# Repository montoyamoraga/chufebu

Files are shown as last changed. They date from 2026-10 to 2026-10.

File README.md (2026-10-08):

# chufebu

## About

chufebu is an open source hardware Eurorack power bus board by [piruetas](https://piruetas.xyz). It distributes ±12V, +5V, CV and GATE to five 16-pin Eurorack power headers, each one paired with its own 4-pin Molex KK-396 connector for testing. The design is made in KiCad 10 using only KiCad's standard libraries. Hardware is licensed under CERN-OHL-P-2.0 and documentation under CC-BY-SA-4.0 (see [LICENSE.md](./LICENSE.md)). Documentation, schematic, board render and bill of materials (in Spanish): <https://piruetas.xyz/chufebu/>.

## Acerca de

Bus de alimentación eurorack de [piruetas](https://piruetas.xyz), hecho en KiCad y publicado como hardware de código abierto.

Documentación, esquemático, placa y Bill of materials: <https://piruetas.xyz/chufebu/>.

## Características

- 5 headers de alimentación Eurorack de 16 pines (2x08), conectados en bus.
- Cada header tiene su conector Molex KK-396 de 4 pines, para pruebas: -12V, GND, +5V y +12V.
- Las líneas CV y GATE también van en bus entre los 5 headers.
- Placa de 100 × 45 mm, 2 capas, con 2 agujeros de montaje M3.
- Solamente usa las bibliotecas estándar de KiCad 10: no hace falta instalar bibliotecas adicionales para abrir o modificar el diseño.

## Pines y manual de uso

Los pines de los headers de 16 pines y de los conectores KK-396, cómo conectar chufebu y las advertencias están en el [manual de uso](https://piruetas.xyz/chufebu/#manual-de-uso).

## Revisiones

- `v0.1 rev-a`: fabricada en octubre 2026, todavía sin probar.

## Estructura del repositorio

- [hardware/chufebu-v-0-rev-a](./hardware/chufebu-v-0-rev-a): proyecto de KiCad (esquemático y placa), los archivos fuente del diseño.
- [hardware/chufebu-v-0-rev-a-fab](./hardware/chufebu-v-0-rev-a-fab): gerbers y archivos de taladrado para fabricar la placa.
- [docs](./docs): documentación, publicada en <https://piruetas.xyz/chufebu/>. Las capturas del esquemático y de la placa, y la tabla de Bill of materials, las genera [kicad-retrata](https://github.com/piruetasxyz/kicad-retrata) en cada push (ver [kicad-retrata.yml](./kicad-retrata.yml)).
- [LICENSES](./LICENSES): textos completos de las licencias.

## Fabricación

piruetas vende chufebu armado y probado.

Como es hardware de código abierto, los archivos fuente de KiCad, los archivos de fabricación de [hardware/chufebu-v-0-rev-a-fab](./hardware/chufebu-v-0-rev-a-fab) y la [Bill of materials](https://piruetas.xyz/chufebu/#bill-of-materials-v01-rev-a) están publicados para que cualquiera pueda estudiar, modificar y fabricar el diseño. piruetas no da soporte para unidades fabricadas o armadas por terceros.

## Créditos

- Aarón Montoya-Moraga: investigación, esquemático, PCB, fabricación y documentación.
- Matías Serrano: revisor experto de esquemáticos y PCBs.

## Licencia

chufebu es (c) 2026 piruetas SpA / Aarón Montoya-Moraga.

- Hardware (`hardware/`): [CERN-OHL-P-2.0](./LICENSES/CERN-OHL-P-2.0.txt).
- Documentación (`docs/`): [CC-BY-SA-4.0](./LICENSES/CC-BY-SA-4.0.txt).
- El nombre, logo y marca de piruetas no están cubiertos por estas licencias: ver [LicenseRef-piruetas-branding](./LICENSES/LicenseRef-piruetas-branding.txt).

Ver [LICENSE.md](./LICENSE.md) para los detalles. El repositorio sigue la especificación [REUSE](https://reuse.software/).

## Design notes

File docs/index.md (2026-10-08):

# chufebu

Bus de alimentación eurorack: 5 headers de 16 pines (2x08) con ±12V y +5V, cada uno con su conector Molex KK-396 de 4 pines.

## Revisiones

- `v0.1 rev-a`: fabricada en octubre 2026, todavía sin probar.

## Manual de uso

### Qué necesitas

- Una fuente de alimentación Eurorack con ±12V (y +5V si algún módulo lo usa).
- Cables planos Eurorack de 16 pines (16-16) o de 10 a 16 pines (10-16), uno por módulo.
- Opcional: 2 tornillos M3 y separadores para montar la placa.

### Conexión

1. Con la fuente **apagada**, conecta la fuente a uno de los headers de 16 pines o a uno de los conectores Molex.
2. Conecta cada módulo con un cable plano a cualquiera de los headers de 16 pines.
3. Orienta cada cable con la **franja roja hacia -12V**. El serigrafiado de la placa marca `-12` en un extremo del header.
4. Revisa todas las conexiones antes de encender la fuente.

### Pines

Header de 16 pines (según el estándar Eurorack de Doepfer):

| Pines | Señal |
| --- | --- |
| 1, 2 | -12V |
| 3 a 8 | GND |
| 9, 10 | +12V |
| 11, 12 | +5V |
| 13, 14 | CV |
| 15, 16 | GATE |

Conector Molex KK-396 de 4 pines:

| Pin | Señal |
| --- | --- |
| 1 | -12V |
| 2 | GND |
| 3 | +5V |
| 4 | +12V |

### Advertencias

- Un cable plano conectado al revés puede dañar el módulo o la fuente. Los headers tienen carcasa con muesca de polarización, pero revisa siempre la franja roja, sobre todo en el lado del módulo.
- Conecta y desconecta cables solamente con la fuente apagada.
- chufebu no tiene fusibles ni protección contra polaridad inversa: la protección depende de la fuente y de cada módulo.
- La corriente total disponible la limita la fuente. Suma el consumo de tus módulos en cada línea y no superes lo que entrega la fuente.

## Esquemático y placa (v0.1 rev-a)

Generados automáticamente por GitHub Actions a partir de `hardware/chufebu-v-0-rev-a/chufebu-v-0-rev-a.kicad_sch` y `.kicad_pcb` en cada push que los modifica.

Esquemático de chufebu v0.1 rev-a

Placa de chufebu v0.1 rev-a

Render 3D de la placa:

<video src="./videos/chufebu-placa-3d-giro.mp4" autoplay loop muted playsinline width="540">Render 3D de la placa de chufebu v0.1 rev-a.</video>

## Bill of materials (v0.1 rev-a)

Generado a partir de `hardware/chufebu-v-0-rev-a/chufebu-v-0-rev-a.kicad_sch`.

<!-- BOM_TABLE_START -->

| Referencias | Cantidad | Valor | Huella | Descripción |
| --- | --- | --- | --- | --- |
| J1, J2, J3, J7, J8 | 5 | Conn_02x08_Odd_Even | Connector_IDC:IDC-Header_2x08_P2.54mm_Vertical | Header de alimentación Eurorack (16 pines): box header 2x08, 2.54 mm, vertical, THT, con carcasa y muesca de polarización ([Thonk](https://www.thonk.co.uk/shop/16pin-power-headers-shrouded/)) |
| J4, J5, J6, J9, J10 | 5 | Conn_01x04_Pin | Connector_Molex:Molex_KK-396_5273-04A_1x04_P3.96mm_Vertical | Conector de alimentación (4 pines): Molex KK-396 5273-04A, 1x04, 3.96 mm, vertical, THT |

10 componentes en total.

<!-- BOM_TABLE_END -->

### Placa (PCB)

Fabricar con los gerbers y archivos de taladrado de [`hardware/chufebu-v-0-rev-a-fab`](https://github.com/piruetasxyz/chufebu/tree/main/hardware/chufebu-v-0-rev-a-fab).

| Especificación | Valor |
| --- | --- |
| Capas | 2 |
| Tamaño | 100 × 45 mm |
| Grosor | 1.6 mm |
| Cobre | 35 µm (1 oz) |
| Acabado superficial | HASL sin plomo (LeadFree HASL) |

## Créditos

- Aarón Montoya-Moraga: investigación, esquemático, PCB, fabricación y documentación.
- Matías Serrano: revisor experto de esquemáticos y PCBs.

## Licencia

El hardware está bajo CERN-OHL-P-2.0 y esta documentación bajo CC-BY-SA-4.0. Ver [LICENSE.md](https://github.com/piruetasxyz/chufebu/blob/main/LICENSE.md).

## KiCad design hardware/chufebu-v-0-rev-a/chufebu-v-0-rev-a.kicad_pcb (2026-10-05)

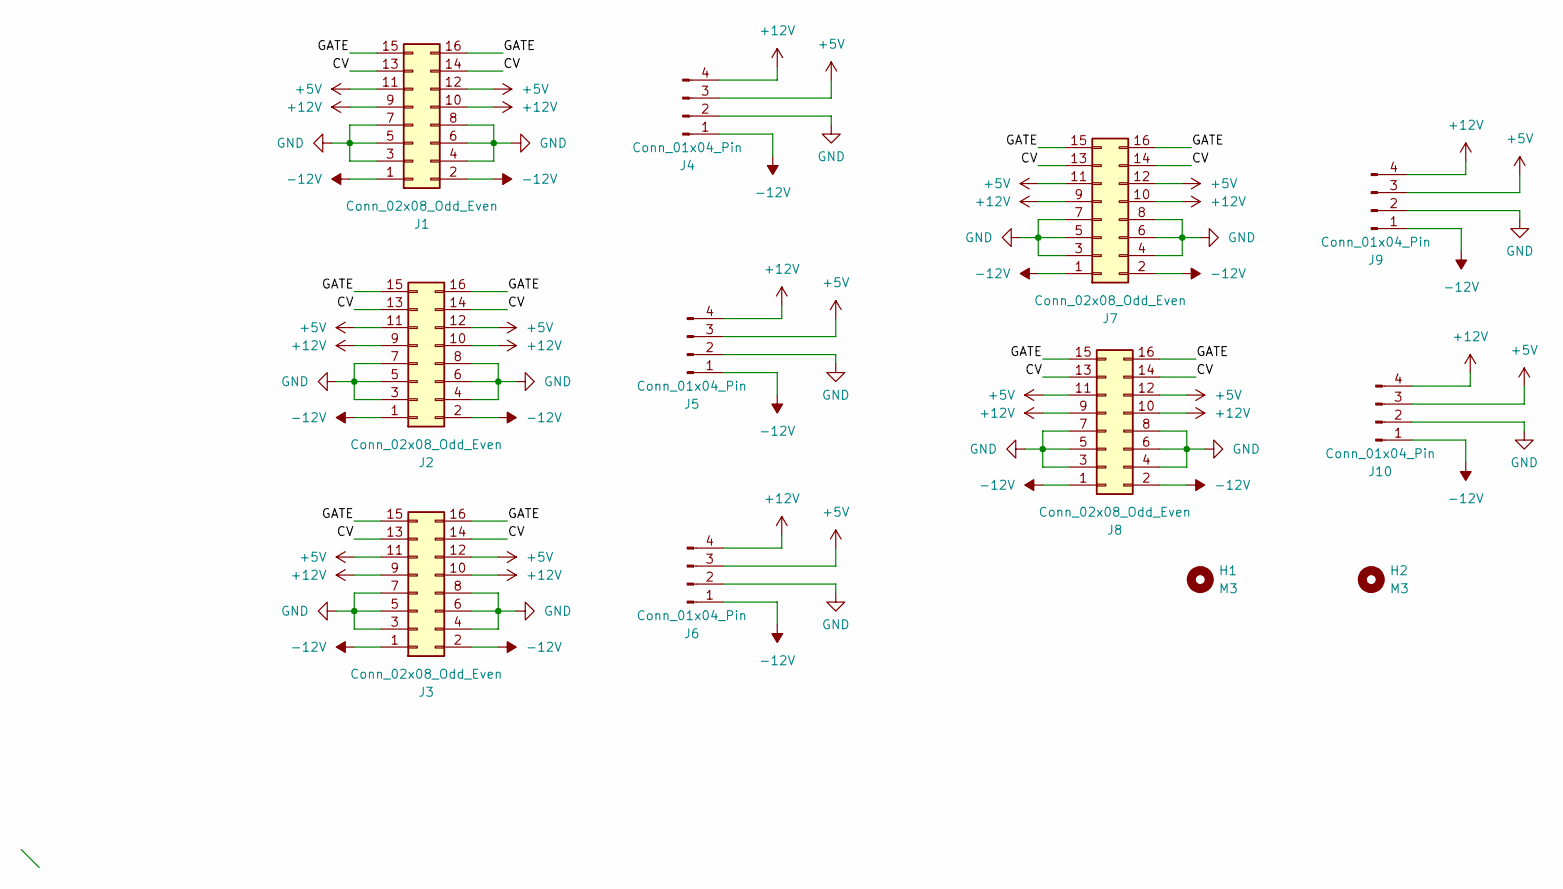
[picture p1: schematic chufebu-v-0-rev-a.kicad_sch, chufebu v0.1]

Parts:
H1, H2: M3; MountingHole_3.2mm_M3
J1, J2, J3, J7, J8: Conn_02x08_Odd_Even; IDC-Header_2x08_P2.54mm_Vertical
J4, J5, J6, J9, J10: Conn_01x04_Pin; Molex_KK-396_5273-04A_1x04_P3.96mm_Vertical

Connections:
+5V: J1.11, J1.12, J2.11, J2.12, J3.11, J3.12, J4.3, J5.3, J6.3, J7.11, J7.12, J8.11, J8.12, J9.3, J10.3
+12V: J1.9, J1.10, J2.9, J2.10, J3.9, J3.10, J4.4, J5.4, J6.4, J7.9, J7.10, J8.9, J8.10, J9.4, J10.4
-12V: J1.1, J1.2, J2.1, J2.2, J3.1, J3.2, J4.1, J5.1, J6.1, J7.1, J7.2, J8.1, J8.2, J9.1, J10.1
/CV: J1.13, J1.14, J2.13, J2.14, J3.13, J3.14, J7.13, J7.14, J8.13, J8.14
/GATE: J1.15, J1.16, J2.15, J2.16, J3.15, J3.16, J7.15, J7.16, J8.15, J8.16
GND: J1.3, J1.4, J1.5, J1.6, J1.7, J1.8, J2.3, J2.4, J2.5, J2.6, J2.7, J2.8, J3.3, J3.4, J3.5, J3.6, J3.7, J3.8, J4.2, J5.2, J6.2, J7.3, J7.4, J7.5, J7.6, J7.7, J7.8, J8.3, J8.4, J8.5, J8.6, J8.7, J8.8, J9.2, J10.2

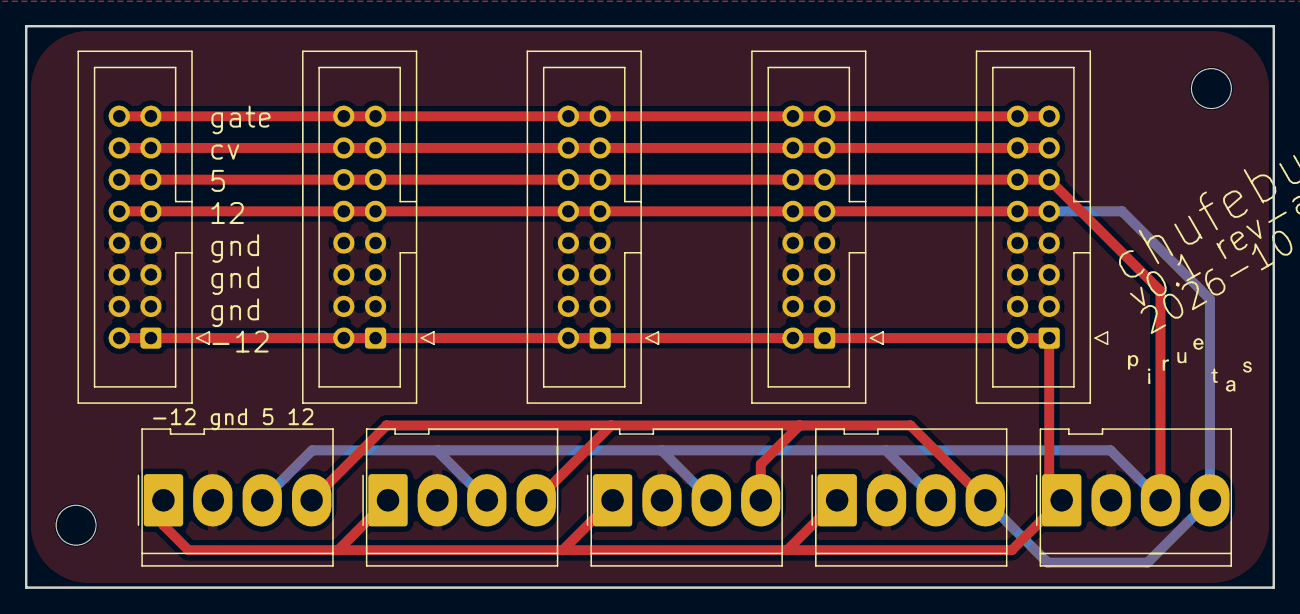
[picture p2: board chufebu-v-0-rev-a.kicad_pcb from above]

Board: 2 copper layers, 100.0 x 45.0 mm, 12 parts (0 on the bottom side), 6 nets.

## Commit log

2026-10-04 agregar v-0-rev-a
    [chufebu-v-0-rev-a.kicad_pcb, chufebu-v-0-rev-a.kicad_sch]
2026-10-04 agregar .gitignore kicad
2026-10-04 agregar infra para docs/
2026-10-04 Actualizar capturas y BOM de esquemáticos y placas [skip ci]
2026-10-05 agregar hardware fab
    [chufebu-v-0-rev-a-B_Cu.gbr, chufebu-v-0-rev-a-B_Mask.gbr, chufebu-v-0-rev-a-B_Paste.gbr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]
2026-10-05 agregar documentacion
    [chufebu-v-0-rev-a.kicad_sch]
2026-10-05 mas docs preparando para nuevo release
    [chufebu-v-0-rev-a.kicad_pcb]
